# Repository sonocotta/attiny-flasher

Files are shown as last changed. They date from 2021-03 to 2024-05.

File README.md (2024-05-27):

# ATtiny Flasher and ATtiny Flasher Kits project files

Open Source Hardware
Open Source Software

<br />


ATtiny Flasher is a handy device that allows you to use your favorite IDEs and debugging tools when developing for the ATtiny microcontroller. Enjoy the classic Arduino development experience while working with bare metal. Whether you’re a design engineer, a hobbyist, or someone who’s just getting started programming MCUs, ATtiny Flasher can help you get from a great idea to a great implementation—without having to port your code to its intended platform when you’re done

After implementing numerous projects using the wonderful ATtiny family of MCUs, we’ve come away with a number of ideas about how to simplify the process. Our goal is to make ATtiny chips as easy to work with as more "grown up" MCUs:
- We want a traditional serial terminal for debugging. Ideally, we want two—one via serial data transferred to the host over USB, and another via the onboard display.
- We want some GPIO LEDs to play with. In fact, why not have LEDs for all GPIOs?
- Speaking of GPIOs, we want to use the RESET pin as a GPIO too, so we'll need an on-board high-voltage programmer.
- In general, we want to upload code to breadboard-connected devices and see that code in action immediately.
- And finally, since our debugger will be connected to a PC via USB, it should handle 3.3 V and 5 V breadboard power rails as well

## How to use it

### Using onboard socket


- Tiny85 to be programmed 
- Breadboard lines connected to Tiny85 pins 
- LEDs connected to Tiny85 pins 
- Tiny85 Serial monitor displayed on LED as well as sent to host PC 
- Host MCU connection to PC 

### Using breadboard


- Tiny85 to be programmed 
- Breadboard lines connected to Tiny85 pins 
- LEDs connected to Tiny85 pins 
- Tiny85 Serial monitor displayed on LED as well as sent to host PC 
- Host MCU connection to PC 

### Using dedicated ATtiny Flasher Kits


- Tiny85 to be programmed 
- Kit components (addressable leds and 2 push buttons) 
- Breadboard lines connected to Tiny85 pins 
- LEDs connected to Tiny85 pins 
- Tiny85 Serial monitor displayed on LED as well as sent to host PC 
- Host MCU connection to PC 

### Standalone, using onboard ISP Header 

- Use ATTiny Flasher like regular ISP Programmer

## ATTiny Flasher Features

- Flash ATtiny85, ATtiny45, ATtiny25, and ATtiny13 via breadboard or onboard header
- Flash the entire Atmega MCU family using the ISP header
- Flash using Arduino IDE, Platformio, or the IDE of your choice
- Two configurable power rails, either 3.3 V or 5 V
- Supports high-voltage programming
- Supports UPDI programming with dedicated header
- Supports TPI programming (after certain HW modifications)
- Six GPIO "weak" LEDs
- Three flash-status LEDs
- Onboard OLED screen connected to target MCU as a live terminal
- Streams serial data to the host PC as if it were connected directly to the target MCU. (Yes, serial on ATtiny. Even ATtiny13!)
- A buffer IC between target and host MCUs only connects the two while flashing
- Open hardware driven by open source software

## Educational ATtiny Project Kits

Having built a product that ticks all of those boxes, we wanted to put ATtiny through its paces, so we designed a collection of simple, affordable, breadboard-compatible project kits that are easy to understand, fun to build, satisfying to use, and well suited to extension and modification. There are five of them in all, and they are a great way to learn about ATtiny programming:

### Traffic Light: ATtiny85-driven "traffic light"



- Onboard ATTiny85 
- 3 bright LEDs: green, yellow, red (PWM controllable) 
- User-programmable button 
- External input or output 

### Rubber Ducky: ATtiny85-driven "USB rubber ducky" tool capable of emulating keyboard & mouse devices



- Onboard ATTiny85 
- 3 user-programmable buttons 
- USB connector with possibility act as PC keyboard or mouse 

### IR Messenger: ATtiny85-driven IR remote transmitter & receiver



- Onboard ATTiny85 
- 3 user-programmable buttons 
- IR recevier (940nm) 
- IR sender (dual 940nm IR LED) 

### Rainbow LED: ATtiny85-driven circle of addressable LEDs



- Onboard ATTiny85 
- 2 user-programmable buttons 
- 8 individually addressable LEDs (WS2820) 
- External input or output 

### Digital Clock: ATtiny85-driven digital clock


- Onboard ATTiny85 
- 2 user-programmable buttons 
- SPI RTC clock (DS1302) with CR1220 battery 
- 128 individually controllable LEDs (forms matrix, stacks on top) 

## Hardware

Please find more information in the [hardware](/hardware) section

## Firmware

Please find more information in the [software](/firmware) section

## Where to buy

Shortly will be available to order from [Mouser](https://mouser.com).

Later on will be shared on [Tindie](https://www.tindie.com/) store.

## Links

- [Crowd Supply campaign](https://www.crowdsupply.com/sonocotta/attiny-flasher)
- [ATtiny Flasher - Product site](https://sonocotta.com/attiny-flasher/)
- [ATtiny Flasher Kit - Product site](https://sonocotta.com/attiny-flasher-kit/)

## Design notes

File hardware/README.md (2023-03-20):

# ATtiny Flasher and ATtiny Flasher Kits hardware 

Open Source Hardware
Open Source Software

This is hardware design files for ATtiny Flasher project



## Features



1. Host MCU - Atmega328P 
2. Host RESET button 
3. Flashing status indicators 
4. Host USB port - for flashing both TARGET and HOST MCUs 
5. Host ISP header - for direct hardware flashing 
6. OLED screen - connected to Host, when used with stock firmware will output TARGET serial data 
7. Programming mode switches 
8. Target ISP flashing header. Compartible with Atmega and ATTiny Family MCUs 
9. Target socket - alternative to flashing within breadboard. Compartible with Tinyx5 and Tiny13 series. 
10. Power Rails and voltage selectors 
11. TARGET port LED indicators 
12. TARGET breadboard connectors 

## Mode Switches



| Num | Function | ON | OFF |
|----|----|----|----|
| 1 | Serial Bridge between Host and Target. When enabled Serial Data from TARGET MCU will be captured on the HOST MCU (115200 baud rate by default). It will be displayed on the OLED screen, also translated to PC via on-boarde Serial-to-USB chip. When enalbed it will pullup PB3 and PB4 ports on the TARGET, therefore might be required to be off | Enabled | Disabled |
| 2 | High voltage programming. When ON it will use built in 12V boost converter to reset HOST MCU into high voltage programming mode. Using this method you can use PB5 port of ATTINY (normally not usable), however make sure that other components of your device can handle 12V during flashing process. | Low voltage, green status LED blink slowly. | High voltage, green status LED blink rapidly |
| 3 | Programming target. When ON incoming Serial data will be interpretet as STK500 commands and translatred accordingly to TARGET MCU. When OFF it will allow to flash HOST MCU using Arduino bootloader (i.e. like any other Atmega) | Flash TARGET | Flash HOST |

## Board Revisions

This comes in multiple revisions, normally revision of the specific board will be clearly visible on the back side of the PCB.



Customers that have participated in the [Crowd Supply campaign](https://www.crowdsupply.com/sonocotta/attiny-flasher)

Current distribution of board revisions looks like this

| Revision | ATtiny Flasher | Revision | ATtiny Flasher Kits  |
|----|----|----|----|
| A | First idea implementation <br />  | | |
| B | Early production run, first one that is breadboard compatible <br />  | | |
| C | Version which started Crowd Supply campaign, still lacking many features however <br />  | A | First run of the Kits <br />  |
| D | Deep revision of the board with High Voltage programming mode added, however not without mistakes :) <br />  | | |
| E | Home work was done to make HVSP work, few improvements <br />  |  | |
| F | Pre-production version of the board, first having UPDI and TPI hardware support. <br />  | B | Fixups after the first run validation <br />  |
| G | **First batch of boards delivered to backers**. Tested with both UPDI and TPI, however require soldering to run in TPI mode. <br />  | C | **First batch of boards delivered to backers**. One issue is still present on the board, that was fixed using bodge resistor <br />  |
| H | Work in progress. Had to replace CH340E chip with CH340G due to inavailability of the first. **Second batch of boards delivered to backers** | D | Work in progress. Issue with Clock kit was found and fixed |
| J | Work in progress. Based on ATMega32u4 host MCU. | | 

## Pin Definitions

### ATtiny Flasher

Generally pins will differ slightly from revision to revision, and will be defined in [boards.h](/firmware/flasher/attiny-flasher/src/boards.h) file Most essential ones are listed below

| PIN DEF | IO | G, H | J
|----|----|----|----|
| OLED SDA,SCL | IO | PC4,PC5 | PD1,PD0 |
| HOST USB | IO | NA | D+,D- |
| HOST SERIAL | IO | PD0,PD1 | NA | 
| TINY SERIAL TX,RX | IO | PD4,PD5 | PD3,PD3 |
| SPI (TINY PROGRAMMING, SELF PROGRAMMING) CLK,MOSI,MISO | IO | PB5,PB3,PB4 | PB1,PB2,PB3 |
| +12V RESET ENABLE | IO | PD2 | PF1
| TARGET RESET PULL UP,DOWN | O | PB2,PC2 | PF0,PF4
| BUFFER ENABLE | O | PC1 (HIGH for ISP, LOW for HVSP) | PB7 (ISP), PE6 (HVSP) |
| STATUS LEDs | O | PD7,PB0,PB1 | NA |
| RGB LED | O | NA | PC6 |
| UPDI IO | IO | PD6 | PD6 | 
| SERIAL ENABLE INPUT | I | PC3 | PF5 

### ATtiny Flasher Kits 

Each usable pin is subscribed directly on the PCB, like on exmaple below



## Links

- [Crowd Supply campaign](https://www.crowdsupply.com/sonocotta/attiny-flasher)
- [ATtiny Flasher - Product site](https://sonocotta.com/attiny-flasher/)
- [ATtiny Flasher Kit - Product site](https://sonocotta.com/attiny-flasher-kit/)

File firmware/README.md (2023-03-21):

# ATtiny Flasher firmware

Open Source Hardware
Open Source Software

## Introduction

All repos are [Platformio](https://platformio.org/) projects, all tested under Ubuntu 20.04 LTS. 

Most of the repos will utilize multiple environments with different settings for different board revisions. Please refer to **platformio.ini** file within project folder.

For each project please find detailed description using links below

## ATtiny Flasher repos

- [attiny-flasher](/firmware/flasher/attiny-flasher) - main ATtiny Flasher firmware repo
- (WIP) [attiny-flasher-updi](/firmware/flasher/attiny-flasher-updi) - adaptation of [jtag2updi](https://github.com/ElTangas/jtag2updi) repo that can be used with Flasher to programm UPDI enabled MCUs
- (WIP) [attiny-flasher-tpi](/firmware/flasher/attiny-flasher-tpi) - TPI communication testing, requires soldering 0-Ohm resistor to be enabled on tyhe hardware level
- (DEBUGGING) [attiny-flasher-arduino-isp](/firmware/flasher/attiny-flasher-arduino-isp) - Original [ArduinoISP](https://www.arduino.cc/en/Tutorial/BuiltInExamples/ArduinoISP) repo adopted to be used with ATtiny Flasher
- (DEBUGGING) [attiny-flasher-test-reset-states](/firmware/flasher/attiny-flasher-test-reset-states) - Firmware that cycle through RESET modes (for HW testing and debuging)
- (DEBUGGING) [attiny-flasher-test-reset-fuses](/firmware/flasher/attiny-flasher-test-reset-fuses) - Firmware that clears out fuse settings on RESET-disabled Tinys (for HWSP testing and debuging)
- (DEBUGGING) [attiny-serial-demo](/firmware/flasher/attiny-serial-demo) - Demo formware for TARGET MCUs that blinks all available LEDs and sends out Serial communications (for HW testing and debuging) 
- (DEBUGGING) [attiny-serial-demo-naked](/firmware/flasher/attiny-serial-demo-naked) - same as above but Framework-less

## ATtiny Flasher Kits repos

- [attiny-bme280-vs-oled](/firmware/kits/attiny-bme280-vs-oled) - Demo firmware that reads BME280 sensor data and sends it to TINY-connected OLED screen
- [attiny-ir-messenger-send-receive](/firmware/kits/attiny-ir-messenger-send-receive) - Receive and send back IR communications (IR Messenger project Kit)
- [attiny-ir-messenger-send](/firmware/kits/attiny-ir-messenger-send) - Send IR communications (IR Messenger project Kit)
- [attiny-led-matrix-demo](/firmware/kits/attiny-led-matrix) - Demo of LED Matrix (Digital Clock kit)
- [attiny-led-matrix-game-of-life](/firmware/kits/attiny-led-matrix-game-of-life) - Demo of LED Matrix [game of life](https://en.wikipedia.org/wiki/Conway%27s_Game_of_Life) (Digital Clock kit)
- [attiny-led-matrix-rtc-clock](/firmware/kits/attiny-led-matrix-rtc-clock) - RTC clock demo firmware (Digital Clock kit)
- [attiny-led-matrix-rtc-clock-set](/firmware/kits/attiny-led-matrix-rtc-clock-set) - 'Set the time' firmware (Digital Clock kit)
- [attiny-led-matrix-text](/firmware/kits/attiny-led-matrix-text) - Demo of the text mode (Digital Clock kit)
- [attiny-rainbow-led](/firmware/kits/attiny-rainbow-led) - Demo firmware of different RGB LED modes (Rainbow Led project kit)
- [attiny-rainbow-led-demo](/firmware/kits/attiny-rainbow-led-demo) - Spinning rainbow demo (Rainbow Led project kit)
- [attiny-rainbow-led-light](/firmware/kits/attiny-rainbow-led-light) - Lightweight library sample that works with Tiny13 (Rainbow Led project kit)
- [attiny-rubber-ducky-keyboard](/firmware/kits/attiny-rubber-ducky-keyboard) - Keyboard emulator demo (Rubber Ducky project kit)
- [attiny-rubber-ducky-mouse](/firmware/kits/attiny-rubber-ducky-mouse) - Mouse emulator demo  (Rubber Ducky project kit)
- [attiny-traffic-light](/firmware/kits/attiny-traffic-light) - Traffic light demo firmware (Traffic Light project kit)

## How to flash

### Recomended: Using Platformio

All firmware files in this repo are [Platformio](https://platformio.org/) projects. This is a preferred tool to be used together with ATtiny Flasher, since it generally hadles better than our beloved Arduino IDE
- It doesn't require manual installation of new boards, it is enough to mention your board in the project configuration and Platformio will pull full framework automatically
- Same goes for the required libraries, just list your dependencies in the project config, Platformio will pull the latest versions
- It is a grown-up code editor, with the possibilities to look up for library sources and adding multiple source files to your project to create good structure.
- It allows to fine-tune build and upload settings as well as many more parameters.

To install Platformio simply add an extension to VS Code

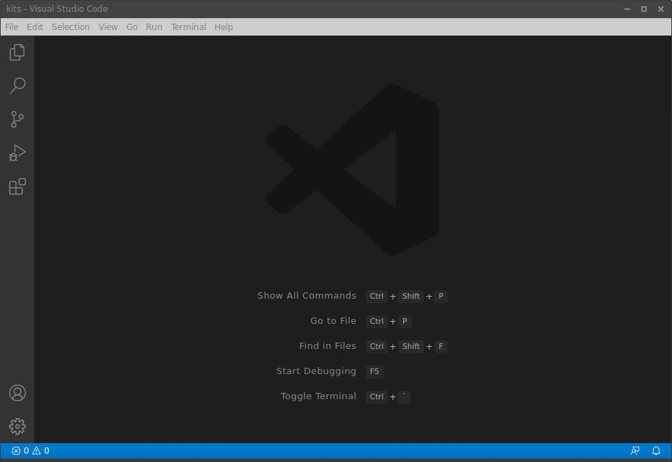
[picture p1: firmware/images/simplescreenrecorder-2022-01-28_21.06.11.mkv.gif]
Install Platformio


#### Flashing Kits using Platformio

Simply open project in the Platformio IDE and run `Platformio: Build` and `Platformio: Upload` tasks. All the relevant settings can be found in `platformio.ini` file in the project folder.

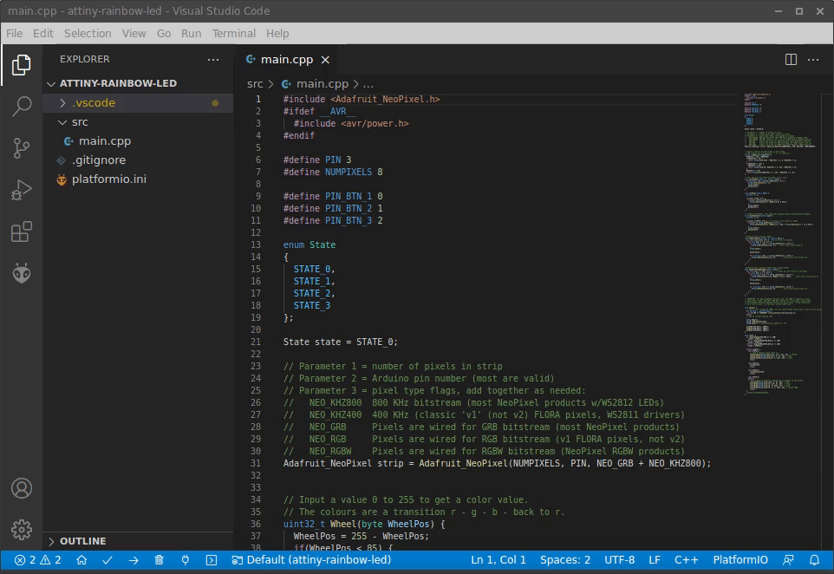
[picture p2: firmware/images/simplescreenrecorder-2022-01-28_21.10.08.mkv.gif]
Build and Upload using Platformio


#### Using Platformio to update Flasher firmware

Open [attiny-flasher](/firmware/flasher/attiny-flasher) folder in Platformio IDE. Find in the Platformio panel your revision of the board (Single letter, usually G, H, J etc is printed in the back side of the PCB). Use the physical switch on the Flasher to select self-programming mode.



Run `Upload` task.

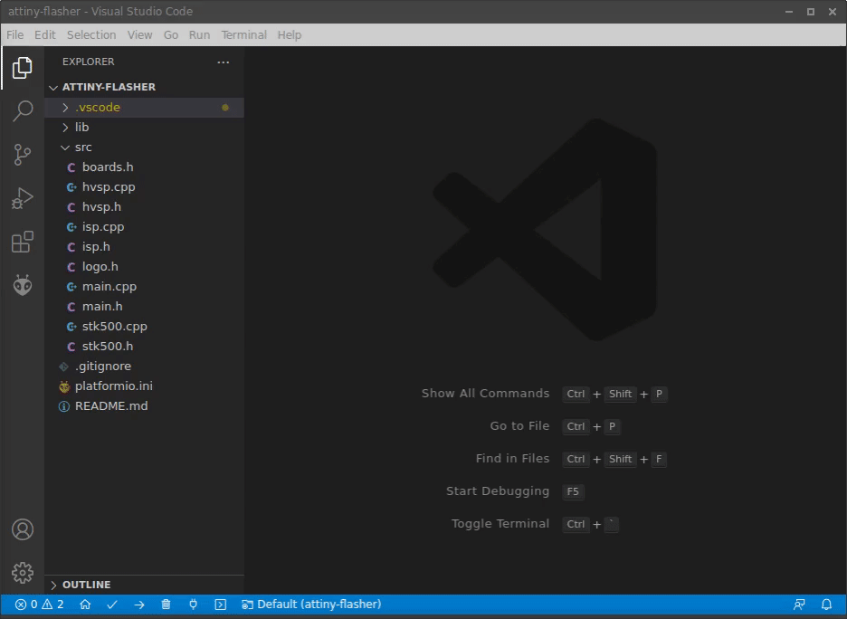
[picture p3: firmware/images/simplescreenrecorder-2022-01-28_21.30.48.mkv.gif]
Updating firmware using Platformio


### Using Arduino IDE

All Flasher Kits are built on ATTINY85 MCU which is not supported by default in Arduino IDE. Therefore first you need to add ATTINY85 support to your Arduino IDe using board manager. Use this link json configuration
```
https://raw.githubusercontent.com/damellis/attiny/ide-1.6.x-boards-manager/package_damellis_attiny_index.json
```

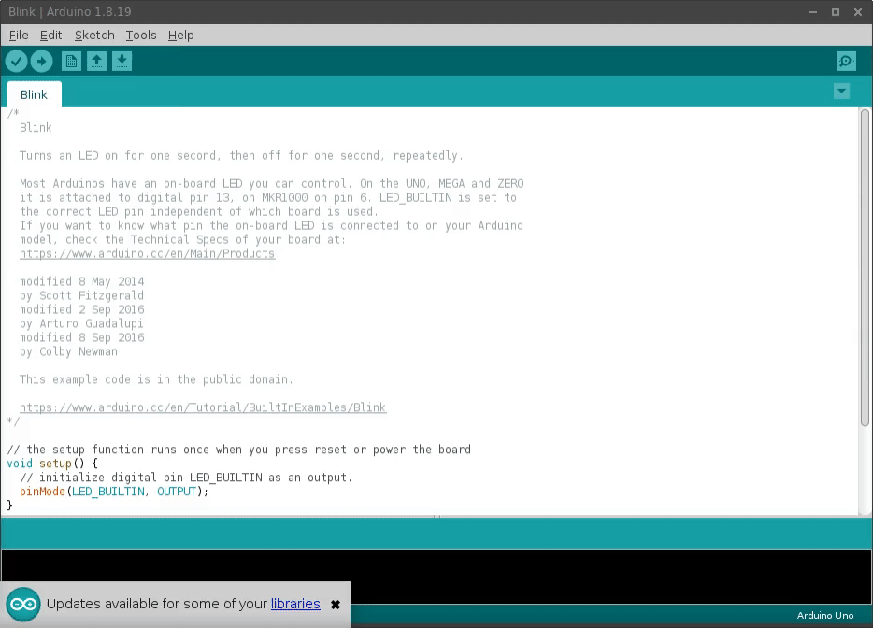
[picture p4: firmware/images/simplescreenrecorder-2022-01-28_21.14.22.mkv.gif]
Adding ATTiny85 support to Arduino IDE


#### Flasher Configuration

By default ATTiny Flasher would expect 115200 baudrate when programming Flasher Projects. Arduino IDE in turn uses 19200 baud rate for the same. This can be fixed by modifying Arduino IDE internal configs (which is not recomended) or by flashing Flasher with updated baud rate

Updating firmware using Platformio

After this is done you may use `Arduino as ISP` programmer in the Arduino IDE with no modifications.

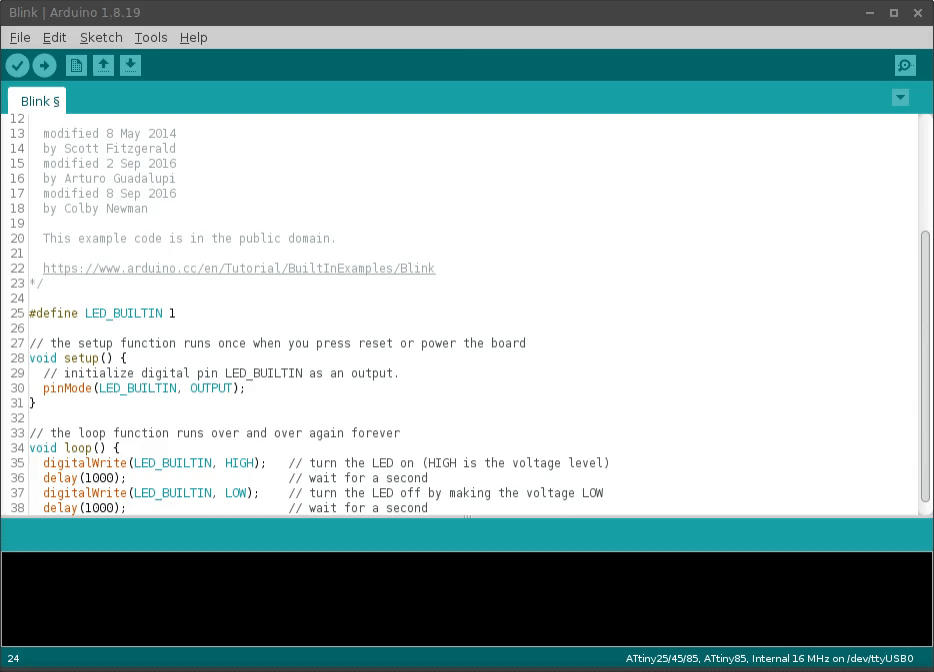
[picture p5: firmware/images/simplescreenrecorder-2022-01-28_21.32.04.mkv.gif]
Flashing using Arduino IDE


### Using avrdude

If you prefer to flash Kits usging pure console, you can use `avrdude` with the proper configuration (similar to what Platformio does under the hood)

Assuming you have built `firmware.hex` and your upload port to be `/dev/ttyUSB0`
```
avrdude -P/dev/ttyUSB0 -b115200 -v -p attiny85 -c stk500v1 -b 115200 -e -D -U flash:w:firmware.hex:i
```

## Links

- [Crowd Supply campaign](https://www.crowdsupply.com/sonocotta/attiny-flasher)
- [ATtiny Flasher - Product site](https://sonocotta.com/attiny-flasher/)
- [ATtiny Flasher Kit - Product site](https://sonocotta.com/attiny-flasher-kit/)

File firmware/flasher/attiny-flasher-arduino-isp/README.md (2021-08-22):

## attiny-flasher-arduino-isp

This is basic ArduinoISP code adopted to be executed on [ATtiny Flasher](https://sonocotta.com/attiny-flasher/).

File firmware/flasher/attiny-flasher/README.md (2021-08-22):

## attiny-flasher

This is firmware code for [ATtiny Flasher](https://sonocotta.com/attiny-flasher/).

It is based on Arduino Framework and currently cupports ISP flasing using STK500v1 protocol in both high voltage and low voltage modes.

I'm trying to keep support of all board revisions to simplify board development and testing, therefore list of build configurations is growing all the time. 

Each new revision of the board is adding some capabilities and more code required to support added features.

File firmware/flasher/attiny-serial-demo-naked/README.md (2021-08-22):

## attiny-serial-demo

This is basic led-blinking and/or serial messaging app that is used to verify [ATtiny Flasher](https://sonocotta.com/attiny-flasher/) capabilities to flash different MCUs. 

It is not using any frameworks but works directly on HW and therefore it is compatible with all the supported MCUs. It is quite usefull for testing and debugging purposes.

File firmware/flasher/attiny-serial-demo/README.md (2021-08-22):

## attiny-serial-demo

This is basic led-blinking and/or serial messaging app that is used to verify [ATtiny Flasher](https://sonocotta.com/attiny-flasher/) capabilities to flash different MCUs. 

It is based on Arduino Framework and therefore is not compatible with all the supported MCUs, but it is quite usefull for testing and debugging purposes

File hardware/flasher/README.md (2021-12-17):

# ATtiny Flasher hardware 

Open Source Hardware
Open Source Software

Please find description on each revision [one level above](/hardware)

## Links

- [Crowd Supply campaign](https://www.crowdsupply.com/sonocotta/attiny-flasher)
- [ATtiny Flasher - Product site](https://sonocotta.com/attiny-flasher/)
- [ATtiny Flasher Kit - Product site](https://sonocotta.com/attiny-flasher-kit/)

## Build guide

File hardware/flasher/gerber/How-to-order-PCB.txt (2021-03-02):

How to Order PCB

Please refer to:
https://docs.easyeda.com/en/PCB/Order-PCB

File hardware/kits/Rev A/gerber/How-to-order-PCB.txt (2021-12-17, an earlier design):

How to Order PCB

Please refer to:
https://docs.easyeda.com/en/PCB/Order-PCB

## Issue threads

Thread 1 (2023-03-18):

Firmware documentation problem

koocotte, 2023-03-18:
In file [attiny-flasher](https://github.com/sonocotta/attiny-flasher)/hardware/README.md file, section "Mode Switches";

Text said "When ON (...) TARGET MCU. When OFF it will allow to flash HOST MCU";

but in the ON column, there is "Flash HOST" and in the OFF one: "Flash TARGET"

Closed 2023-03-20.

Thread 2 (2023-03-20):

Flashing firmware result in "error" LED

koocotte, 2023-03-20:
Hello.

I don't know if here is the best place to try to solve this sort of problem.

I tried to re-flash my attiny-flasher rev G to use 19200 bps to work with the arduino IDE.

As specified on firmware/README.md, I put all 3 switch 'OFF' and updated hardware/README.md with "#define BAUDRATE_IN 19200".
In platformio, the Build and Upload task where successfull.

But on reboot; there is no more draw on the screen and the "ERR" led is red.

Here are the Upload log (don't know if it's useful)

[attiny-upload.txt](https://github.com/sonocotta/attiny-flasher/files/11015535/attiny-upload.txt)

anabolyc, 2023-03-20:
Hi @koocotte .
Quick health check:
- please make sure your HW version is G
- which folder (project) you took for the repo?

koocotte, 2023-03-21:
Hello,

"ATTINY FLASHER
REV G" is written on the back of the board

Here is the repo i use:
```
seb@octarine:~/tmp/attiny-flasher/firmware/flasher/attiny-flasher$ git remote -v
origin  https://github.com/sonocotta/attiny-flasher/ (fetch)
origin  https://github.com/sonocotta/attiny-flasher/ (push)
seb@octarine:~/tmp/attiny-flasher/firmware/flasher/attiny-flasher$ git pull
Already up to date.
```
In Platformio (the ant-face tab), I use the file `attiny-flasher/firmware/flasher/attiny-flasher/platformio.ini` and the task `atmega328-tiny-rev-g/General/Upload`

anabolyc, 2023-03-21:
Hi @koocotte. I just notices, that I did quite a few changes in the fork, rather than in this repo. I just committed "sync" changeset. It doesn't address your issue directly, but it will update your code to the version I'm using.
Could you please pull the latest code and flash firmware once again. Please note if dependency graph will stay the same or become shorter.

Closed 2023-03-22.

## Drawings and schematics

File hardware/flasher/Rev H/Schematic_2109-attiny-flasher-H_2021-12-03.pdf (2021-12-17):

LED INDICATORS | FLASHING BUFFER

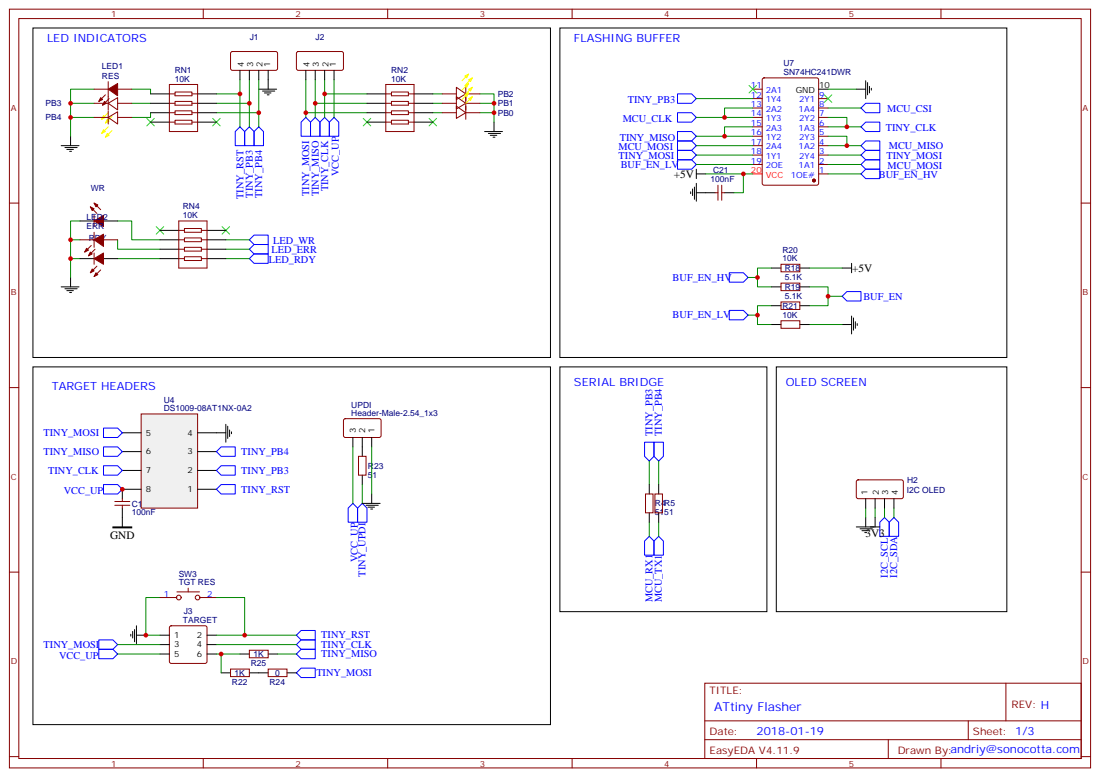
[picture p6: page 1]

HOST MCU | MODE SWITCHES

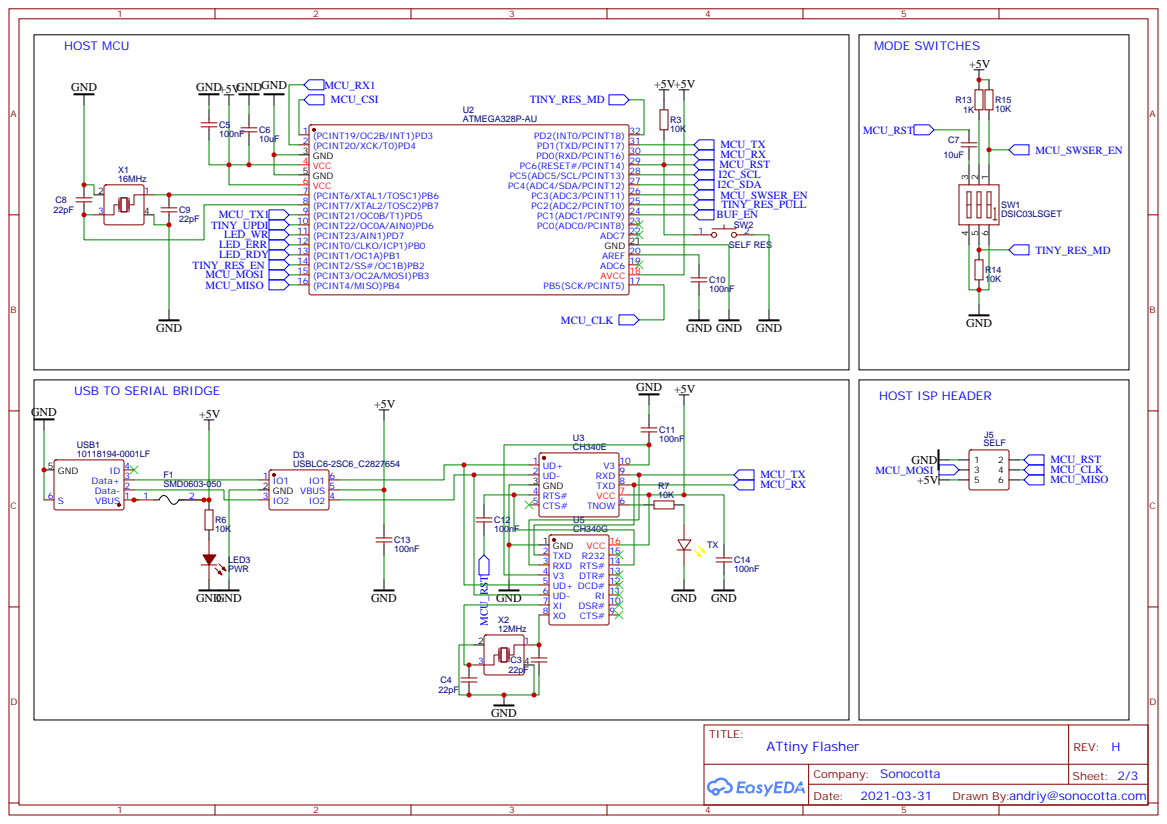
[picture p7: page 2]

DSR# 10 RI 11 DCD# 12 DTR# 13 RTS# 14 R232 15 VCC 16

Drawn By:andriy@sonocotta.com

## RESET TARGET CIRCUIT

## POWER INDICATORS

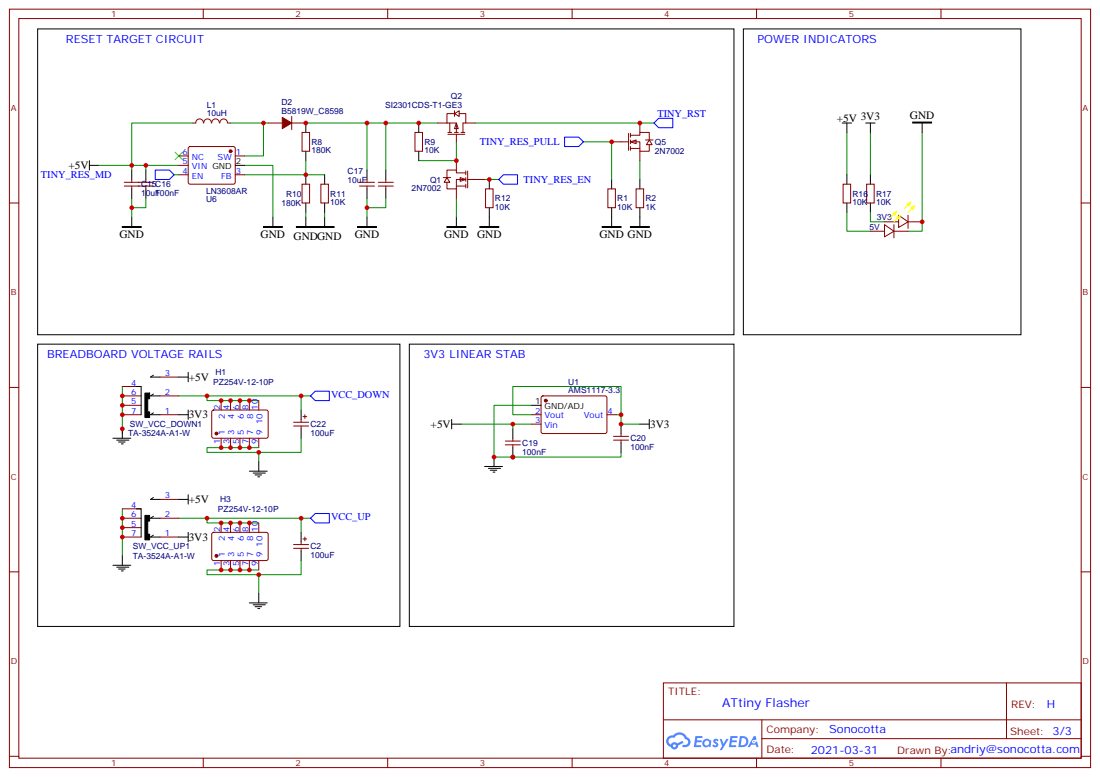
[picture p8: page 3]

Drawn By:andriy@sonocotta.com

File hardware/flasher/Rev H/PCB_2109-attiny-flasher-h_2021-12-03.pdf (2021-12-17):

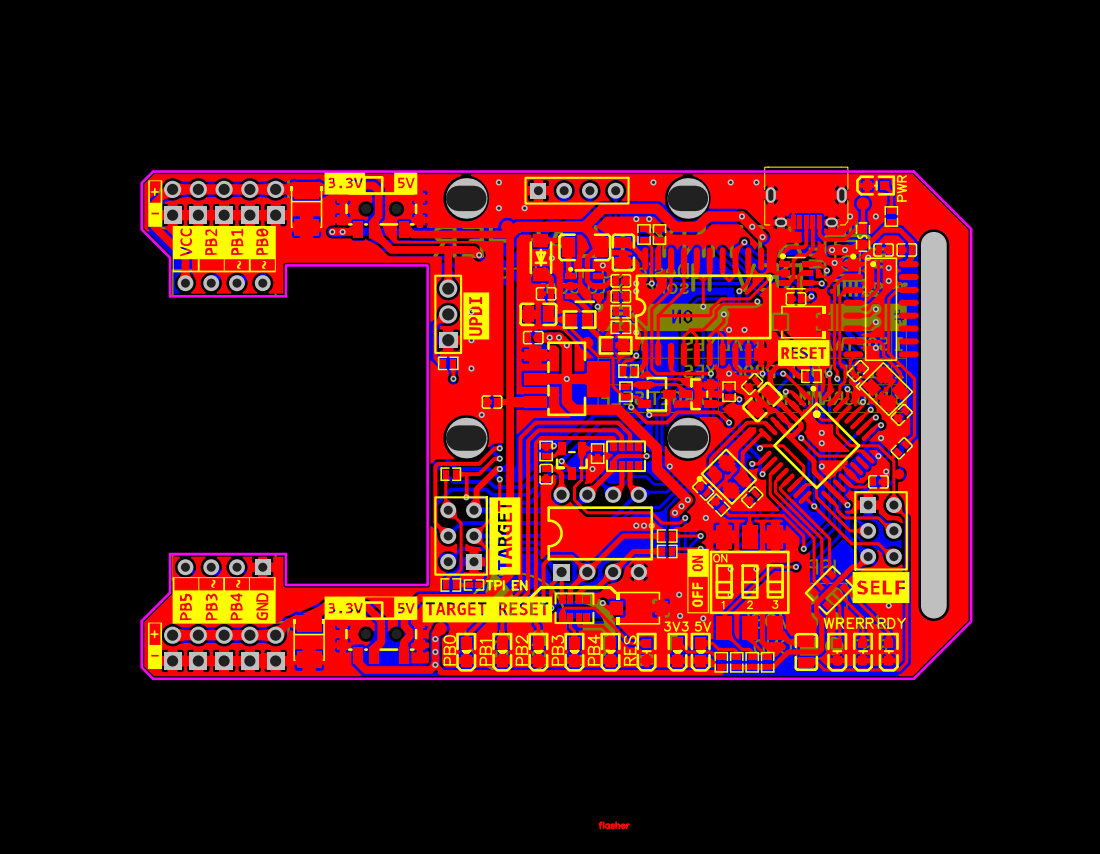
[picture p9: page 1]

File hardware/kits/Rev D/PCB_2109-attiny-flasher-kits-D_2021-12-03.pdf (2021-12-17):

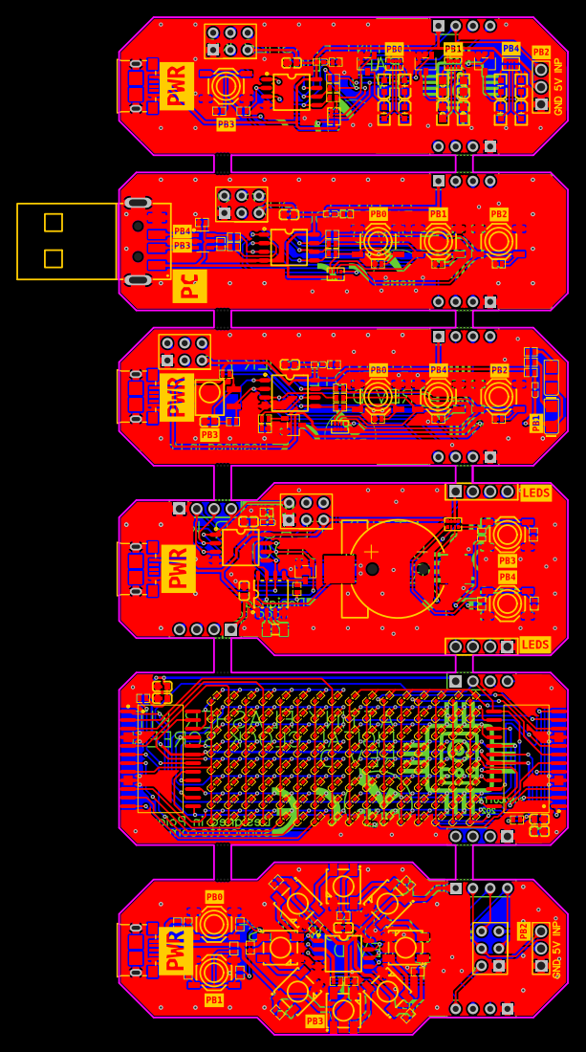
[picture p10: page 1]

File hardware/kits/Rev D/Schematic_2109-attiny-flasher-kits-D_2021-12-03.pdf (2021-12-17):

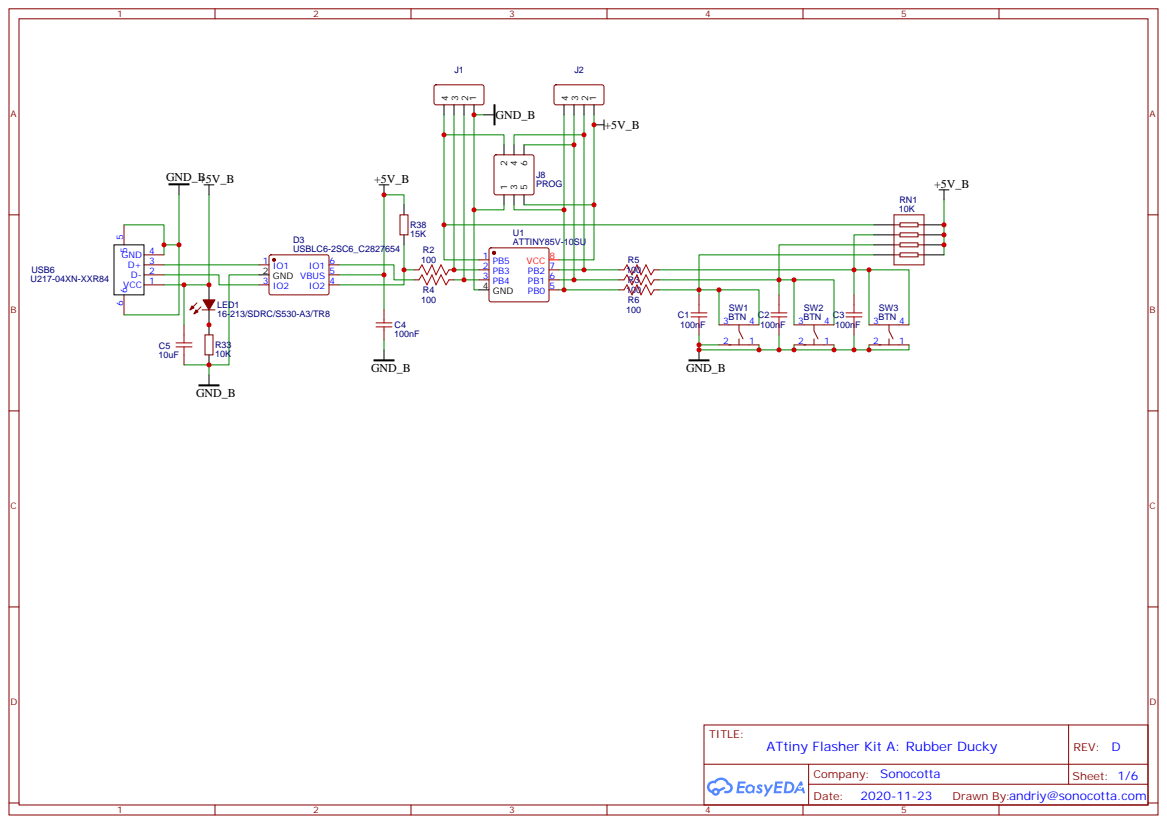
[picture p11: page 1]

Drawn By:andriy@sonocotta.com

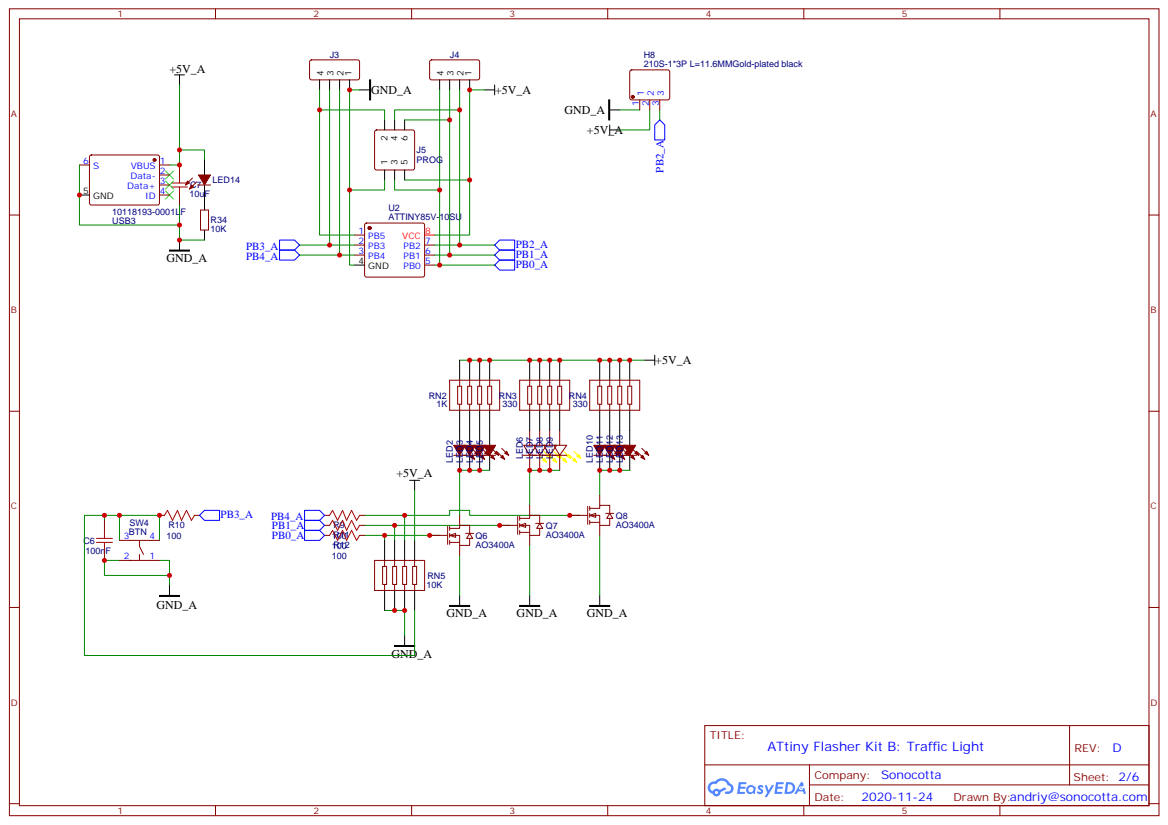
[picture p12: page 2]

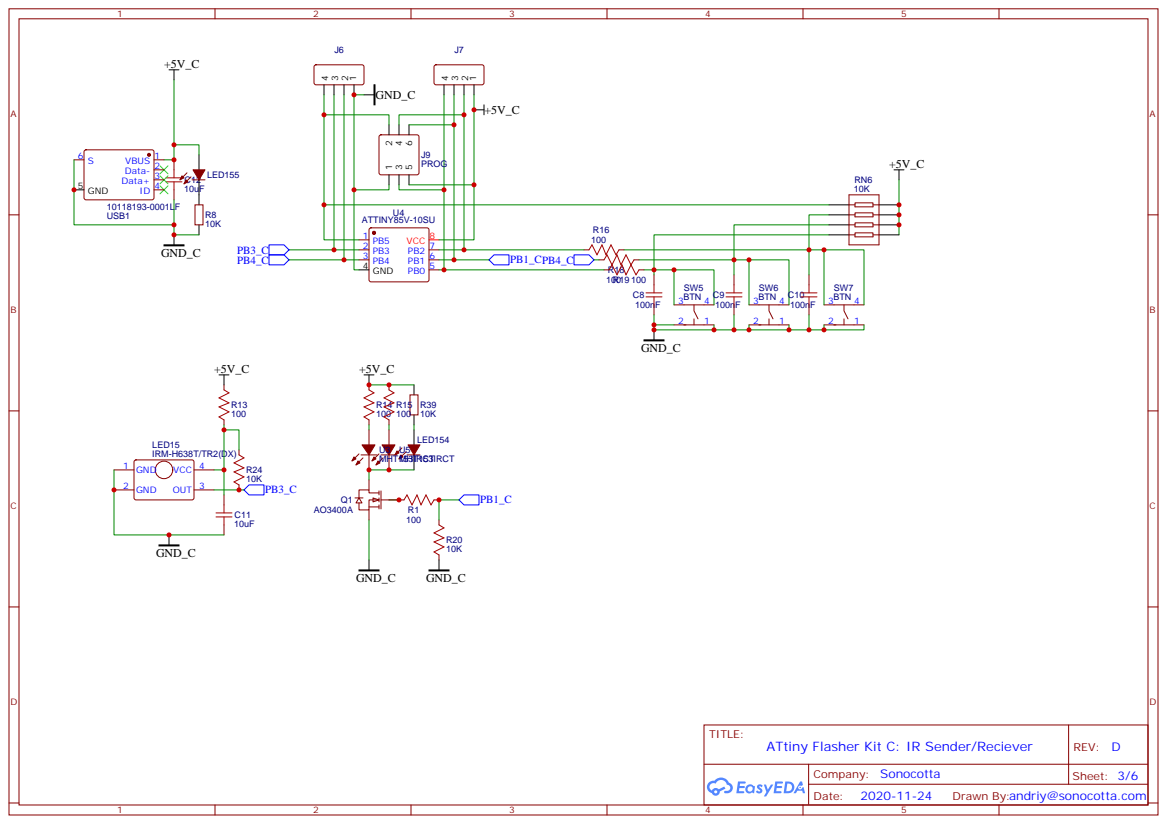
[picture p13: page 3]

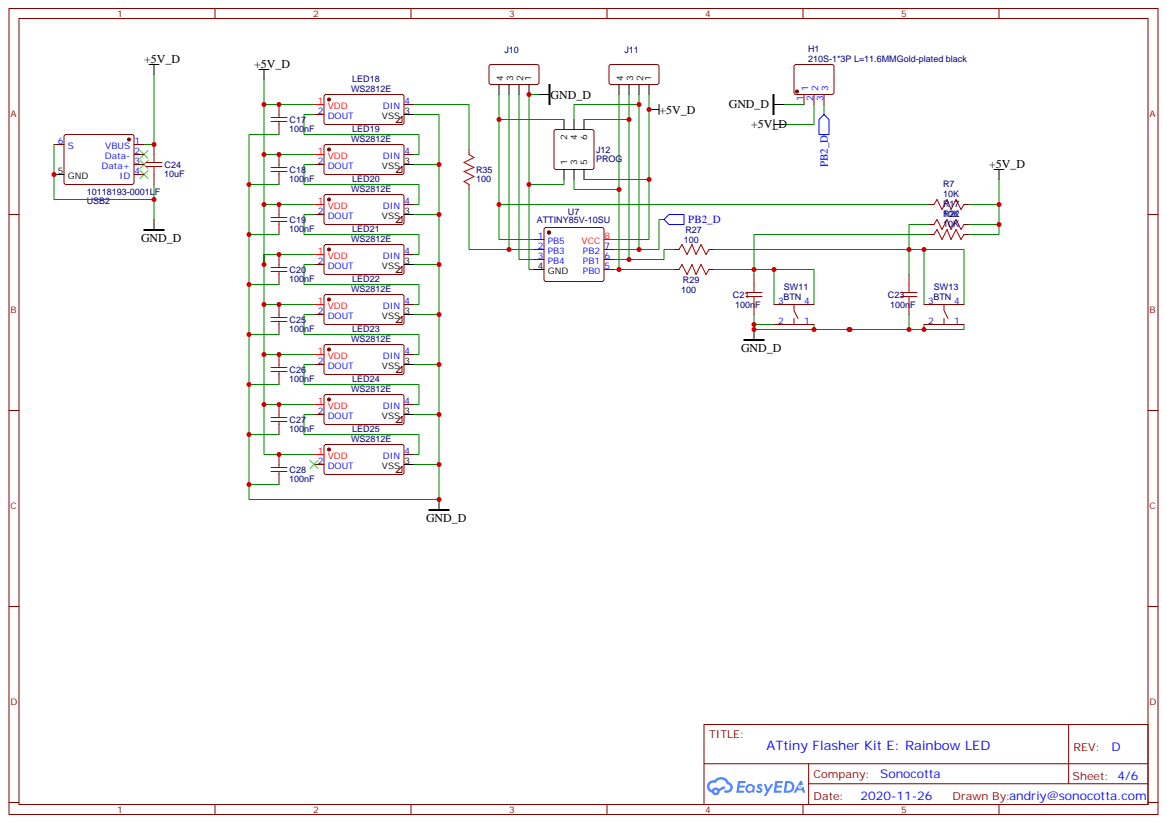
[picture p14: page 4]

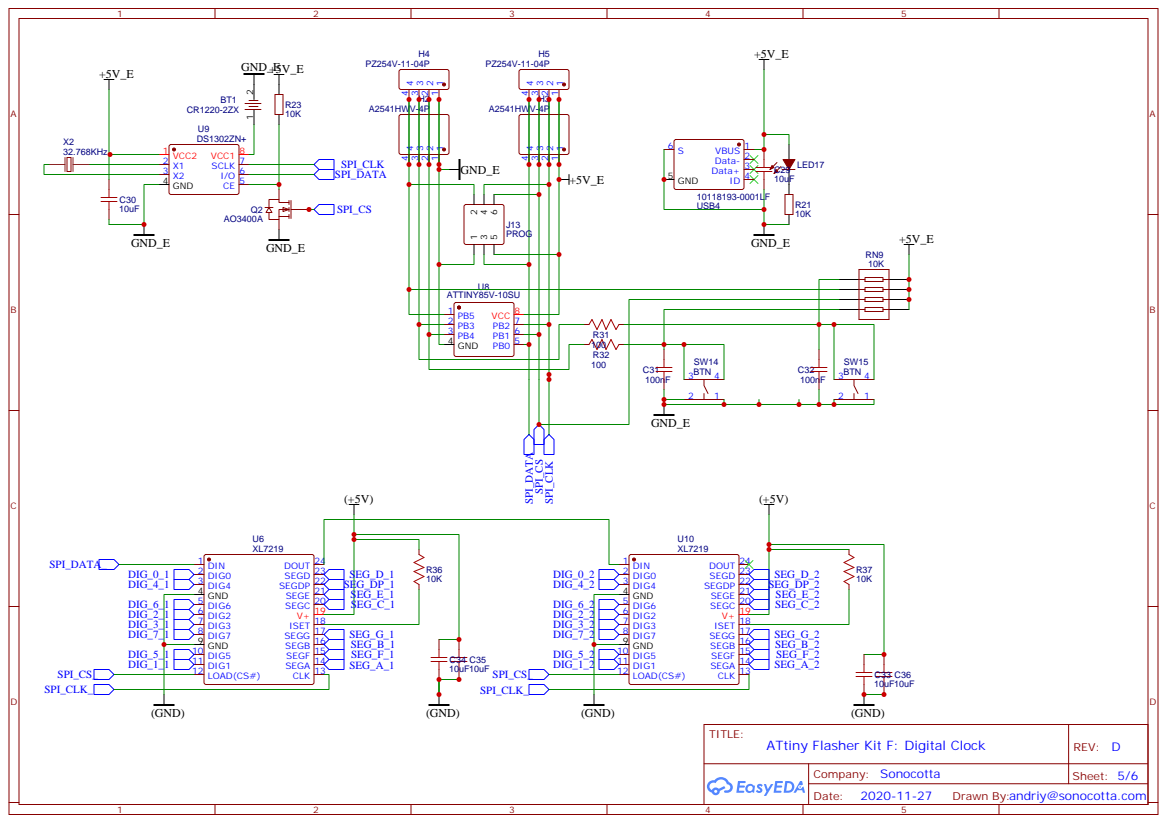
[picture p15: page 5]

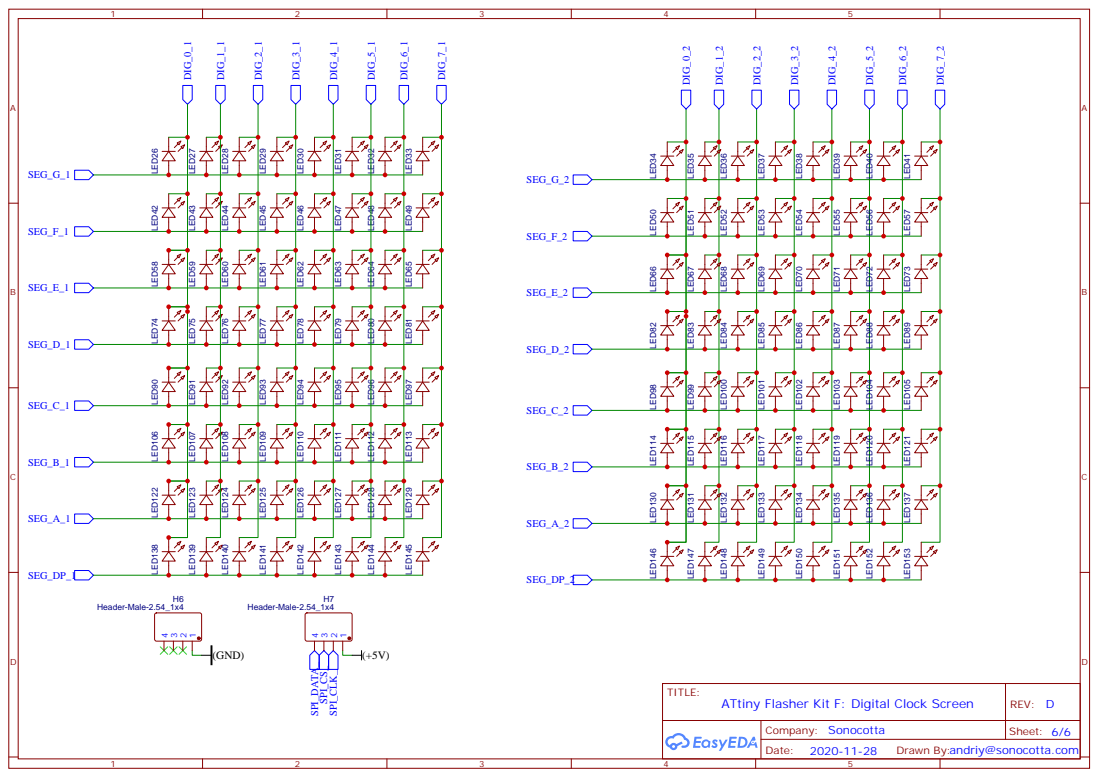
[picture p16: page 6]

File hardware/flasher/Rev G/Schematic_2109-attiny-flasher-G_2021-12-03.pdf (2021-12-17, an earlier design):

LED INDICATORS | FLASHING BUFFER

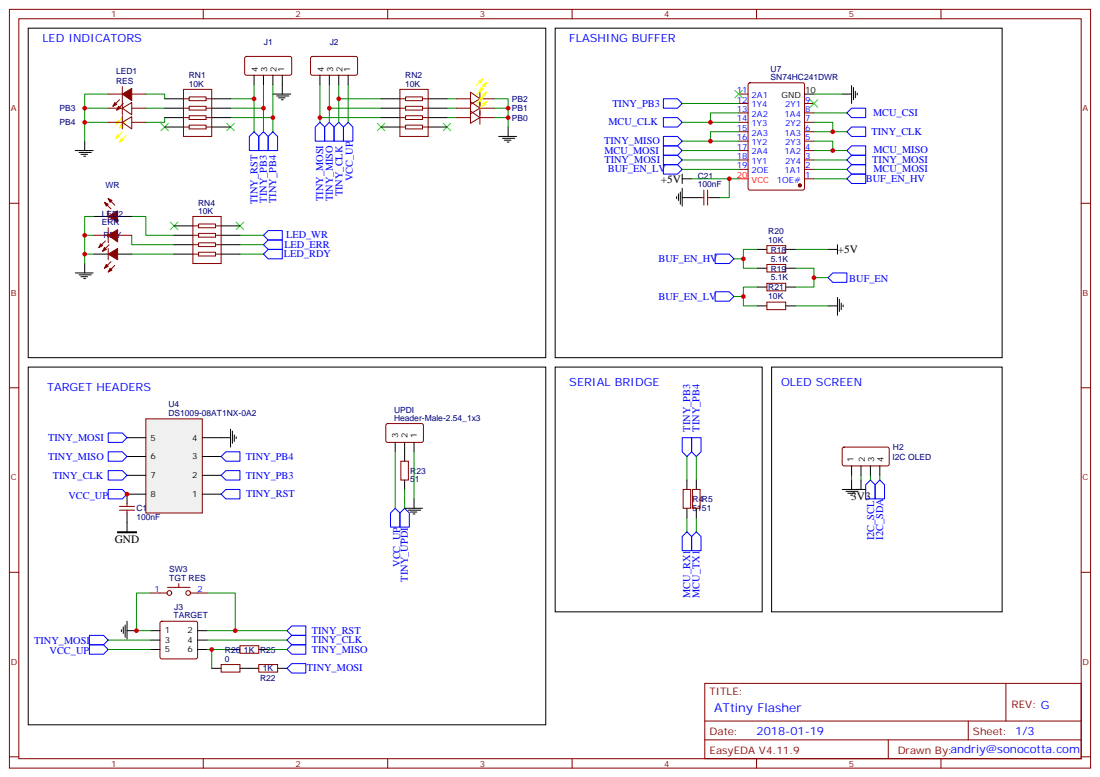
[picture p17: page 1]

HOST MCU | MODE SWITCHES


HOST ISP HEADER USB TO SERIAL BRIDGE

Drawn By:andriy@sonocotta.com

## RESET TARGET CIRCUIT

## POWER INDICATORS


Drawn By:andriy@sonocotta.com



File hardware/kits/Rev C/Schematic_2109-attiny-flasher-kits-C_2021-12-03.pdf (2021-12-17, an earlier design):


Drawn By:andriy@sonocotta.com









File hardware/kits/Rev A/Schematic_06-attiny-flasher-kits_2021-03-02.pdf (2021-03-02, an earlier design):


Drawn By: andrey.malyshenko@gmail.com


Drawn By: andrey.mal






Drawn By: andrey.mal

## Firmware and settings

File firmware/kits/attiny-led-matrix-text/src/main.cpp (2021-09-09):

#include <Arduino.h>
#include "main.h"

#define SCREEN_CNT 2

#define byte uint8_t
#define FONT8X8 font8x8_ib8x8u

const byte ROTATION_0 = 0;   // wires at the left
const byte ROTATION_90 = 1;  // wires at the top
const byte ROTATION_180 = 2; // wires at the right
const byte ROTATION_270 = 3; // wires at the bottom

const byte *getImage(byte ch)
{
    if (ch < 128)
    {
        return FONT8X8[ch];
    }
    if (ch >= 128 && ch < 160)
    {
        // miscellaneous
        ch -= 128;
        if (ch < sizeof(font8x8_misc) / 8)
        {
            return font8x8_misc[ch];
        }
        return FONT8X8[0]; // valeur par défaut
    }
    return FONT8X8[ch - 160 + 128];
}

inline byte reverseBits(byte b)
{
    byte inv = 0;
    for (int j = 0; j < 8; ++j)
    {
        inv <<= 1;
        if (b & 0x1)
            inv |= 1;
        b >>= 1;
    }
    return inv;
}

void rotateChar90(const byte *image, byte newb[8])
{
    for (int i = 0; i < 8; ++i)
    {
        newb[i] = 0;
        for (int j = 0; j < 8; ++j)
        {
            byte b = pgm_read_byte_near(image + j);
            newb[i] |= (b & (1 << i)) ? 1 << (7 - j) : 0;
        }
    }
}

void rotateChar270(const byte *image, byte newb[8])
{
    for (int i = 0; i < 8; ++i)
    {
        newb[i] = 0;
        for (int j = 0; j < 8; ++j)
        {
            byte b = pgm_read_byte_near(image + j);
            newb[i] |= (b & (1 << (7 - i))) ? 1 << j : 0;
        }
    }
}

void printChar(LedControl &lc, int addr, byte ch)
{
    const byte *image = getImage(ch);
    for (int i = 0; i < 8; i++)
    {
        byte b = pgm_read_byte_near(image + i);
        lc.setRow(addr, i, b);
    }
}

void printChar(LedControl &lc, int addr, byte ch, byte rotate)
{
    const byte *image = getImage(ch);
    if (rotate == ROTATION_0)
    {
        for (int i = 0; i < 8; ++i)
        {
            byte b = pgm_read_byte_near(image + i);
            lc.setRow(addr, i, b);
        }
    }
    else if (rotate == ROTATION_90)
    {
        byte newb[8];
        rotateChar90(image, newb);
        for (int i = 0; i < 8; ++i)
        {
            lc.setRow(addr, i, newb[i]);
        }
    }
    else if (rotate == ROTATION_180)
    {
        for (int i = 0; i < 8; ++i)
        {
            byte b = pgm_read_byte_near(image + 7 - i);
            lc.setRow(addr, i, reverseBits(b));
        }
    }
    else if (rotate == ROTATION_270)
    {
        byte newb[8];
        rotateChar270(image, newb);
        for (int i = 0; i < 8; ++i)
        {
            lc.setRow(addr, i, newb[i]);
        }
    }
}

class StrBase
{
  protected:
    const char *str_;
    size_t len_;

  public:
    StrBase() = default;

  protected:
    size_t length() const
    {
        return len_;
    }
    virtual byte at(size_t) const = 0;

  private:
    void displayString0(LedControl &lc, int addr, unsigned long wait) const;
    void displayString90(LedControl &lc, int addr, unsigned long wait) const;
    void displayString180(LedControl &lc, int addr, unsigned long wait) const;
    void displayString270(LedControl &lc, int addr, unsigned long wait) const;

  public:
    void displayString(LedControl &lc, int addr, unsigned long wait, bool scroll, byte rotate = ROTATION_0) const
    {
        if (scroll)
        {
            if (rotate == ROTATION_0)
                displayString0(lc, addr, wait);
            else if (rotate == ROTATION_90)
                displayString90(lc, addr, wait);
            else if (rotate == ROTATION_180)
                displayString180(lc, addr, wait);
            else if (rotate == ROTATION_270)
                displayString270(lc, addr, wait);
        }
        else
        {
            for (size_t i = 0; i < length(); ++i)
            {
                printChar(lc, addr, at(i), rotate);
                delay(wait);
            }
        }
    }
    void printString(LedControl &lc, int addr, unsigned long wait, byte rotate = ROTATION_0) const;
};

// string stored in data segment
class StrD : public StrBase
{
  public:
    explicit StrD(const char *str)
    {
        str_ = str;
        len_ = strlen(str);
    }

    virtual byte at(size_t i) const override
    {
        if (i < len_)
            return str_[i];
        return 0;
    }
};

// string with PROGMEM attribute (stored in code segment)
class StrP : public StrBase
{
  public:
    explicit StrP(const char *str)
    {
        str_ = str;
        len_ = strlen_P(str);
    }

    virtual byte at(size_t i) const override
    {
        if (i < len_)
            return pgm_read_byte_near(str_ + i);
        return 0;
    }
};

void StrBase::displayString0(LedControl &lc, int addr, unsigned long wait) const
{
    wait /= 8;
    unsigned o;
    for (o = 0; o < length() - 1; ++o)
    {
        const byte *image1 = getImage(at(o));
        const byte *image2 = getImage(at(o + 1));

        for (int offset = 0; offset < 8; ++offset)
        {
            for (int i = 0; i < 8; ++i)
            {
                byte b;

                if (offset == 0)
                {
                    b = pgm_read_byte_near(image1 + i);
                }
                else
                {
                    byte b1 = pgm_read_byte_near(image1 + i);
                    byte b2 = pgm_read_byte_near(image2 + i);
                    b = (b1 << offset) | (b2 >> (8 - offset));
                }

                lc.setRow(addr, i, b);
            }
            delay(wait);
        }
    }

    // affiche le dernier caractère entièrement
    printChar(lc, addr, at(o));
    delay(wait);
}

void StrBase::displayString90(LedControl &lc, int addr, unsigned long wait) const
{
    wait /= 8;
    unsigned o;
    for (o = 0; o < length() - 1; ++o)
    {
        const byte *image1 = getImage(at(o));
        const byte *image2 = getImage(at(o + 1));

        byte newb1[8];
        byte newb2[8];
        rotateChar90(image1, newb1);
        rotateChar90(image2, newb2);

        for (int offset = 0; offset < 8; ++offset)
        {
            for (int i = 0; i < 8; ++i)
            {
                if (offset <= i)
                    lc.setRow(addr, i, newb1[i - offset]);
                else
                    lc.setRow(addr, i, newb2[i + 8 - offset]);
            }
            delay(wait);
        }
    }

    // affiche le dernier caractère entièrement
    printChar(lc, addr, at(o), ROTATION_90);
    delay(wait);
}

void StrBase::displayString180(LedControl &lc, int addr, unsigned long wait) const
{
    wait /= 8;
    unsigned o;
    for (o = 0; o < length() - 1; ++o)
    {
        const byte *image1 = getImage(at(o));
        const byte *image2 = getImage(at(o + 1));

        for (int offset = 0; offset < 8; ++offset)
        {
            //for (int i = 7; i >= 0; --i)
            for (int i = 0; i < 8; ++i)
            {
                byte b;

                if (offset == 0)
                {
                    b = pgm_read_byte_near(image1 + 7 - i);
                }
                else
                {
                    byte b1 = pgm_read_byte_near(image1 + 7 - i);
                    byte b2 = pgm_read_byte_near(image2 + 7 - i);
                    b = (b1 << offset) | (b2 >> (8 - offset));
                }

                lc.setRow(addr, i, reverseBits(b));
            }
            delay(wait);
        }
    }

    // affiche le dernier caractère entièrement
    printChar(lc, addr, at(o), ROTATION_180);
    delay(wait);
}

void StrBase::displayString270(LedControl &lc, int addr, unsigned long wait) const
{
    wait /= 8;
    unsigned o;
    for (o = 0; o < length() - 1; ++o)
    {
        const byte *image1 = getImage(at(o));
        const byte *image2 = getImage(at(o + 1));

        byte newb1[8];
        byte newb2[8];
        rotateChar270(image1, newb1);
        rotateChar270(image2, newb2);

        for (int offset = 0; offset < 8; ++offset)
        {
            for (int i = 0; i < 8; ++i)
            {
                if (offset - (7 - i) <= 0)
                    lc.setRow(addr, i, newb1[7 + offset - (7 - i)]);
                else
                    lc.setRow(addr, i, newb2[offset - (7 - i) - 1]);
            }
            delay(wait);
        }
    }

    // affiche le dernier caractère entièrement
    printChar(lc, addr, at(o), ROTATION_270);
    delay(wait);
}

void StrBase::printString(LedControl &lc, int addr, unsigned long wait, byte rotate) const
{
    for (size_t i = 0; i < length(); ++i)
    {
        printChar(lc, addr, at(i), rotate);
        delay(wait);
    }
}

// wrappers

// PROGMEM strings
void displayString_P(LedControl &lc, const char *str, int addr, unsigned long wait, bool scroll, byte rotate)
{
    StrP(str).displayString(lc, addr, wait, scroll, rotate);
}

// DATA strings
void displayString(LedControl &lc, const char *str, int addr, unsigned long wait, bool scroll, byte rotate)
{
    StrD(str).displayString(lc, addr, wait, scroll, rotate);
}

const char texte[] PROGMEM = "Hello, World!";

void setup()
{
    for (uint8_t addr = 0; addr < SCREEN_CNT; addr++) {
        lc.shutdown(addr, false);
        /* Set the brightness to a medium values */
        lc.setIntensity(addr, 8);
        /* and clear the display */
        lc.clearDisplay(addr);
    }
}

void loop()
{
    for (uint8_t addr = 0; addr < SCREEN_CNT; addr++) {
        displayString_P(lc, texte, addr, 1500, true, ROTATION_90);
    }
}

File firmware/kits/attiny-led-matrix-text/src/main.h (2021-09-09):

#ifndef Main_h
#define Main_h

#include "LedControl.h"

#define PIN_LED_CLK    2
#define PIN_LED_CS     1
#define PIN_LED_DATA   0

#define PIN_BTN_A   3
#define PIN_BTN_B   4

#define LED_MATRIX_CNT 4

LedControl lc = LedControl(PIN_LED_DATA, PIN_LED_CLK, PIN_LED_CS, LED_MATRIX_CNT);

#include <avr/pgmspace.h>

//
// FACE_NAME "IBM BIOS 8x8"
//
// 0-31,127 : Code page 437, cf. https://en.wikipedia.org/wiki/Code_page_437
// 32-126   : ASCII
// 160-255  : ISO-8859-1, cf. https://en.wikipedia.org/wiki/ISO/IEC_8859-1

const uint8_t font8x8_ib8x8u[224][8] PROGMEM = {
    // ---------------------------  0-127 ---------------------------
    {0x00, 0x00, 0x00, 0x00, 0x00, 0x00, 0x00, 0x00},  // 0000 (uni0000.dup1)
    {0x7e, 0x81, 0xa5, 0x81, 0xbd, 0x99, 0x81, 0x7e},  // 0001 (uni0001)
    {0x7e, 0xff, 0xdb, 0xff, 0xc3, 0xe7, 0xff, 0x7e},  // 0002 (uni0002)
    {0x6c, 0xfe, 0xfe, 0xfe, 0x7c, 0x38, 0x10, 0x00},  // 0003 (uni0003)
    {0x10, 0x38, 0x7c, 0xfe, 0x7c, 0x38, 0x10, 0x00},  // 0004 (uni0004)
    {0x38, 0x7c, 0x38, 0xfe, 0xfe, 0x7c, 0x38, 0x7c},  // 0005 (uni0005)
    {0x10, 0x10, 0x38, 0x7c, 0xfe, 0x7c, 0x38, 0x7c},  // 0006 (uni0006)
    {0x00, 0x00, 0x18, 0x3c, 0x3c, 0x18, 0x00, 0x00},  // 0007 (uni0007)
    {0xff, 0xff, 0xe7, 0xc3, 0xc3, 0xe7, 0xff, 0xff},  // 0008 (uni0008)
    {0x00, 0x3c, 0x66, 0x42, 0x42, 0x66, 0x3c, 0x00},  // 0009 (uni0009)
    {0xff, 0xc3, 0x99, 0xbd, 0xbd, 0x99, 0xc3, 0xff},  // 000a (uni000A)
    {0x0f, 0x07, 0x0f, 0x7d, 0xcc, 0xcc, 0xcc, 0x78},  // 000b (uni000B)
    {0x3c, 0x66, 0x66, 0x66, 0x3c, 0x18, 0x7e, 0x18},  // 000c (uni000C)
    {0x3f, 0x33, 0x3f, 0x30, 0x30, 0x70, 0xf0, 0xe0},  // 000d (uni000D)
    {0x7f, 0x63, 0x7f, 0x63, 0x63, 0x67, 0xe6, 0xc0},  // 000e (uni000E)
    {0x99, 0x5a, 0x3c, 0xe7, 0xe7, 0x3c, 0x5a, 0x99},  // 000f (uni000F)
    {0x80, 0xe0, 0xf8, 0xfe, 0xf8, 0xe0, 0x80, 0x00},  // 0010 (uni0010)
    {0x02, 0x0e, 0x3e, 0xfe, 0x3e, 0x0e, 0x02, 0x00},  // 0011 (uni0011)
    {0x18, 0x3c, 0x7e, 0x18, 0x18, 0x7e, 0x3c, 0x18},  // 0012 (uni0012)
    {0x66, 0x66, 0x66, 0x66, 0x66, 0x00, 0x66, 0x00},  // 0013 (uni0013)
    {0x7f, 0xdb, 0xdb, 0x7b, 0x1b, 0x1b, 0x1b, 0x00},  // 0014 (uni0014)
    {0x3e, 0x63, 0x38, 0x6c, 0x6c, 0x38, 0xcc, 0x78},  // 0015 (uni0015)
    {0x00, 0x00, 0x00, 0x00, 0x7e, 0x7e, 0x7e, 0x00},  // 0016 (uni0016)
    {0x18, 0x3c, 0x7e, 0x18, 0x7e, 0x3c, 0x18, 0xff},  // 0017 (uni0017)
    {0x18, 0x3c, 0x7e, 0x18, 0x18, 0x18, 0x18, 0x00},  // 0018 (uni0018)
    {0x18, 0x18, 0x18, 0x18, 0x7e, 0x3c, 0x18, 0x00},  // 0019 (uni0019)
    {0x00, 0x18, 0x0c, 0xfe, 0x0c, 0x18, 0x00, 0x00},  // 001a (uni001A)
    {0x00, 0x30, 0x60, 0xfe, 0x60, 0x30, 0x00, 0x00},  // 001b (uni001B)
    {0x00, 0x00, 0xc0, 0xc0, 0xc0, 0xfe, 0x00, 0x00},  // 001c (uni001C)
    {0x00, 0x24, 0x66, 0xff, 0x66, 0x24, 0x00, 0x00},  // 001d (uni001D)
    {0x00, 0x18, 0x3c, 0x7e, 0xff, 0xff, 0x00, 0x00},  // 001e (uni001E)
    {0x00, 0xff, 0xff, 0x7e, 0x3c, 0x18, 0x00, 0x00},  // 001f (uni001F)
    {0x00, 0x00, 0x00, 0x00, 0x00, 0x00, 0x00, 0x00},  // 0020 (space)
    {0x30, 0x78, 0x78, 0x30, 0x30, 0x00, 0x30, 0x00},  // 0021 (exclam)
    {0x6c, 0x6c, 0x6c, 0x00, 0x00, 0x00, 0x00, 0x00},  // 0022 (quotedbl)
    {0x6c, 0x6c, 0xfe, 0x6c, 0xfe, 0x6c, 0x6c, 0x00},  // 0023 (numbersign)
    {0x30, 0x7c, 0xc0, 0x78, 0x0c, 0xf8, 0x30, 0x00},  // 0024 (dollar)
    {0x00, 0xc6, 0xcc, 0x18, 0x30, 0x66, 0xc6, 0x00},  // 0025 (percent)
    {0x38, 0x6c, 0x38, 0x76, 0xdc, 0xcc, 0x76, 0x00},  // 0026 (ampersand)
    {0x60, 0x60, 0xc0, 0x00, 0x00, 0x00, 0x00, 0x00},  // 0027 (quotesingle)
    {0x18, 0x30, 0x60, 0x60, 0x60, 0x30, 0x18, 0x00},  // 0028 (parenleft)
    {0x60, 0x30, 0x18, 0x18, 0x18, 0x30, 0x60, 0x00},  // 0029 (parenright)
    {0x00, 0x66, 0x3c, 0xff, 0x3c, 0x66, 0x00, 0x00},  // 002a (asterisk)
    {0x00, 0x30, 0x30, 0xfc, 0x30, 0x30, 0x00, 0x00},  // 002b (plus)
    {0x00, 0x00, 0x00, 0x00, 0x00, 0x30, 0x30, 0x60},  // 002c (comma)
    {0x00, 0x00, 0x00, 0xfc, 0x00, 0x00, 0x00, 0x00},  // 002d (hyphen)
    {0x00, 0x00, 0x00, 0x00, 0x00, 0x30, 0x30, 0x00},  // 002e (period)
    {0x06, 0x0c, 0x18, 0x30, 0x60, 0xc0, 0x80, 0x00},  // 002f (slash)
    {0x7c, 0xc6, 0xce, 0xde, 0xf6, 0xe6, 0x7c, 0x00},  // 0030 (zero)
    {0x30, 0x70, 0x30, 0x30, 0x30, 0x30, 0xfc, 0x00},  // 0031 (one)
    {0x78, 0xcc, 0x0c, 0x38, 0x60, 0xc4, 0xfc, 0x00},  // 0032 (two)
    {0x78, 0xcc, 0x0c, 0x38, 0x0c, 0xcc, 0x78, 0x00},  // 0033 (three)
    {0x1c, 0x3c, 0x6c, 0xcc, 0xfe, 0x0c, 0x1e, 0x00},  // 0034 (four)
    {0xfc, 0xc0, 0xf8, 0x0c, 0x0c, 0xcc, 0x78, 0x00},  // 0035 (five)
    {0x38, 0x60, 0xc0, 0xf8, 0xcc, 0xcc, 0x78, 0x00},  // 0036 (six)
    {0xfc, 0xcc, 0x0c, 0x18, 0x30, 0x30, 0x30, 0x00},  // 0037 (seven)
    {0x78, 0xcc, 0xcc, 0x78, 0xcc, 0xcc, 0x78, 0x00},  // 0038 (eight)
    {0x78, 0xcc, 0xcc, 0x7c, 0x0c, 0x18, 0x70, 0x00},  // 0039 (nine)
    {0x00, 0x30, 0x30, 0x00, 0x00, 0x30, 0x30, 0x00},  // 003a (colon)
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

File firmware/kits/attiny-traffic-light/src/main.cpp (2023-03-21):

#include <Arduino.h>

#ifdef REV_A
#define PIN_BTN 4
#define PIN_GRN 0
#define PIN_YLW 1
#define PIN_RED 2
#ifdef FEATURES_ARROW
#define PIN_ARR 3
#endif
#endif

#ifdef REV_B
#define PIN_BTN 3
#define PIN_GRN 4
#define PIN_YLW 1
#define PIN_RED 0
#ifdef FEATURES_ARROW
#define PIN_ARR 2
#endif
#endif

#ifdef FEATURES_ARROW
#define PIN_ARR 3
#endif

#define LED_OFF LOW
#define LED_ON HIGH

#define BTN_OFF HIGH
#define BTN_ON LOW

#define OFF_AFTER_SEC 5

enum State
{
  OFF,
  ON,
  GREEN,
  YELLOW_TO_RED,
  RED,
  YELLOW_TO_GREEN,
  TO_OFF
};

State current_state = OFF;

void do_demo_pin(uint8_t pin)
{
  for (uint8_t x = 0; x < 0xff; x++)
  {
    analogWrite(pin, x);
    delay(1);
  }
  for (uint8_t x = 0xff; x > 0; x--)
  {
    analogWrite(pin, x);
    delay(1);
  }
  analogWrite(pin, 0);
}

void setup()
{
  pinMode(PIN_BTN, INPUT);
  pinMode(PIN_GRN, OUTPUT);
  pinMode(PIN_YLW, OUTPUT);
  pinMode(PIN_RED, OUTPUT);

#ifdef FEATURES_ARROW
  pinMode(PIN_ARR, OUTPUT);
  digitalWrite(PIN_ARR, LOW);
#endif

#ifdef DEMO_MODE
  while (1)
  {
    do_demo_pin(PIN_GRN);
    do_demo_pin(PIN_YLW);
    do_demo_pin(PIN_RED);
  }
#endif
}

uint16_t last_off = 0;
#ifdef FEATURES_ARROW
uint8_t arrow_flag = 0;
uint8_t arrow_seq = 0;
#endif

void loop()
{
  uint8_t btn_state = digitalRead(PIN_BTN);
  if (btn_state == BTN_OFF)
  {
    last_off = millis() >> 10;
  }
  if (btn_state == BTN_ON)
  {
    uint16_t now = millis() >> 10;
    uint16_t sec_on = now - last_off;
    // check if long press
    if (sec_on >= OFF_AFTER_SEC)
    {
      current_state = TO_OFF;
    }
  }

  switch (current_state)
  {
  case TO_OFF:
    if (btn_state == BTN_ON)
    {
      digitalWrite(PIN_YLW, OFF);
      digitalWrite(PIN_RED, OFF);
      digitalWrite(PIN_GRN, OFF);
    }
    if (btn_state == BTN_OFF)
    {
      current_state = OFF;
    }
    break;

  case OFF:
    if (btn_state == BTN_OFF)
    {
      uint16_t seconds = millis() >> 10;
      uint8_t yellow_state = seconds % 2;
      digitalWrite(PIN_YLW, yellow_state);
    }
    if (btn_state == BTN_ON)
    {
      current_state = ON;
    }
    break;

  case ON:
    if (btn_state == BTN_ON)
    {
      digitalWrite(PIN_YLW, ON);
    }
    if (btn_state == BTN_OFF)
    {
      current_state = GREEN;
    }
    break;

  case GREEN:
    if (btn_state == BTN_OFF)
    {
      digitalWrite(PIN_RED, LED_OFF);
      digitalWrite(PIN_YLW, LED_OFF);
      digitalWrite(PIN_GRN, LED_ON);
    }
    if (btn_state == BTN_ON)
    {
      current_state = YELLOW_TO_RED;
    }
    break;

  case YELLOW_TO_RED:
    if (btn_state == BTN_ON)
    {
      digitalWrite(PIN_GRN, LED_OFF);
      digitalWrite(PIN_YLW, LED_ON);
    }
    if (btn_state == BTN_OFF)
    {
      current_state = RED;
    }
    break;

  case RED:
    if (btn_state == BTN_OFF)
    {
      digitalWrite(PIN_YLW, LED_OFF);
      digitalWrite(PIN_RED, LED_ON);
#ifdef FEATURES_ARROW
      if (arrow_flag == 0)
      {
        bool should_switch_on = arrow_seq++ % 2 == 0;
        //millis() % 2 == 0;
        if (should_switch_on)
          digitalWrite(PIN_ARR, LED_ON);
        arrow_flag = 1;
      }
#endif
    }
    if (btn_state == BTN_ON)
    {
      current_state = YELLOW_TO_GREEN;
#ifdef FEATURES_ARROW
      arrow_flag = 0;
#endif
    }
    break;

  case YELLOW_TO_GREEN:
    if (btn_state == BTN_ON)
    {
#ifdef FEATURES_ARROW
      digitalWrite(PIN_ARR, LED_OFF);
#endif
      digitalWrite(PIN_RED, LED_ON);
      digitalWrite(PIN_YLW, LED_ON);
    }
    if (btn_state == BTN_OFF)
    {
      current_state = GREEN;
    }
    break;
  }
}

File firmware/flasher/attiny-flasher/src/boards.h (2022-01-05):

#ifndef _BOARDS_H_
#define _BOARDS_H_

// Connection with host PC (HW serial)
#define BAUDRATE_IN 115200

// Connection with target MCU (SW serial)
#define BAUDRATE_OUT 115200

// ======= REVISION CAPABILITES DEFINITION ============

#if defined(FLASHER_REV_C)
#define BUF_74HC125D
// Tiny-linked Serial pins
#define PIN_SERIAL_RX 5
#define PIN_SERIAL_TX 4 // sometimes 2
#endif

#if defined(FLASHER_REV_D)
#define BUF_74HC125D
// Tiny-linked Serial pins
#define PIN_SERIAL_RX 5
#define PIN_SERIAL_TX 4
#define SERIAL_SENSOR_EN
#define SERIAL_SENSOR_PIN A3
#endif

#if defined(FLASHER_REV_E) || defined(FLASHER_REV_F) || defined(FLASHER_REV_G) || defined(FLASHER_REV_H)
#define REV_D_TWO_PIN_RESET
#define HVSP_PROGRAMMER
#define SERIAL_SENSOR_EN
#define SERIAL_SENSOR_PIN A3
#define BUF_74HC241

// Tiny-linked Serial pins
#define PIN_SERIAL_RX 4
#define PIN_SERIAL_TX 5

// ============== RESET MODES DEFINITION ==============
#define RESET_SENSOR_EN
#define RESET_SENSOR_PIN 2
#define RESET_SENSOR_WRITE(X)          \
    pinMode(RESET_SENSOR_PIN, OUTPUT); \
    digitalWrite(RESET_SENSOR_PIN, X);
#define RESET_SENSOR_READ \
    pinMode(RESET_SENSOR_PIN, INPUT);
#endif

#ifdef MEGAFLASHER_REV_F
#define MEGAFLASHER
#define BUF_74HC125D
// Tiny-linked Serial pins
#define PIN_SERIAL_RX 4
#define PIN_SERIAL_TX 5
#define SERIAL_SENSOR_EN
#define SERIAL_SENSOR_PIN A3
#endif

#define RESET 10
#if defined(REV_D_TWO_PIN_RESET)
#define RESET_PULL A2 // Need another pin to pull it down properly
#endif

// Enable output buffer, active HIGH on 74HC126D, active LOW on 74HC125D
#if defined(FLASHER_REV_F) || defined(FLASHER_REV_G) || defined(FLASHER_REV_H) || defined(MEGAFLASHER_REV_F) 
#define PIN_BUFEN A1
#else
#define PIN_BUFEN 6
#endif

#ifdef BUF_74HC126D
#define _BUFFER_HV_PROG ;
#define _BUFFER_INIT            \
    pinMode(PIN_BUFEN, OUTPUT); \
#define _BUFFER_ON          \
        digitalWrite(PIN_BUFEN, HIGH);
#define _BUFFER_OFF \
    digitalWrite(PIN_BUFEN, LOW);
#endif

#ifdef BUF_74HC125D
#define _BUFFER_HV_PROG ;
#define _BUFFER_INIT \
    pinMode(PIN_BUFEN, OUTPUT);
#define _BUFFER_ON \
    digitalWrite(PIN_BUFEN, LOW);
#define _BUFFER_OFF \
    digitalWrite(PIN_BUFEN, HIGH);
#endif

#ifdef BUF_74HC241
#define _BUFFER_HV_PROG         \
    pinMode(PIN_BUFEN, OUTPUT); \
    digitalWrite(PIN_BUFEN, LOW); \
    if (sserial != NULL) pinMode(PIN_SERIAL_TX, INPUT) // SERIAL_TX connected to HVSP_CSI
#define _BUFFER_INIT ;
#define _BUFFER_ON              \
    pinMode(PIN_BUFEN, OUTPUT); \
    digitalWrite(PIN_BUFEN, HIGH);
#define _BUFFER_OFF \
    pinMode(PIN_BUFEN, INPUT); \
    if (sserial != NULL) pinMode(PIN_SERIAL_TX, OUTPUT) // SERIAL_TX connected to HVSP_CSI
#endif

#if defined(REV_D_TWO_PIN_RESET)
#define _RESET_INIT         \
    pinMode(RESET, OUTPUT); \
    pinMode(RESET_PULL, OUTPUT);
#define _RESET_HIGH_12             \
    RESET_SENSOR_WRITE(HIGH);      \
    digitalWrite(RESET_PULL, LOW); \
    digitalWrite(RESET, HIGH);
#define _RESET_HIGH                \
    RESET_SENSOR_WRITE(LOW);       \
    digitalWrite(RESET_PULL, LOW); \
    digitalWrite(RESET, HIGH);
#define _RESET_LOW                  \
    digitalWrite(RESET, LOW);       \
    digitalWrite(RESET_PULL, HIGH); \
    RESET_SENSOR_WRITE(LOW);
#define _RESET_Z                   \
    digitalWrite(RESET_PULL, LOW); \
    digitalWrite(RESET, LOW);      \
    RESET_SENSOR_READ;
#else
#define _RESET_INIT ;
#define _RESET_HIGH_12 ;
#define _RESET_HIGH         \
    pinMode(RESET, OUTPUT); \
    digitalWrite(RESET, HIGH);
#define _RESET_LOW          \
    pinMode(RESET, OUTPUT); \
    digitalWrite(RESET, LOW);
#define _RESET_Z \
    pinMode(RESET, INPUT);
#endif

// ======= INDICATION PINS ============================

#define PULSE_TIME 10
#define LED_HB 9    // Heartbeat
#define LED_ERR 8   // Error
#define LED_PMODE 7 // Programm

#if defined(OLED_LIB_ADAFRUIT) || defined(OLED_LIB_TINY)
#define OLED_ENABLE
#endif

// ============== PIN MODES DEFINITION ==============

#define PIN_MOSI MOSI
#define PIN_MISO MISO
#define PIN_SCK SCK

#define SETUP_PINS_ISP         \
    pinMode(PIN_MOSI, OUTPUT); \
    pinMode(PIN_MISO, INPUT);  \
    pinMode(PIN_SCK, OUTPUT);

#define PIN_SCI 3
#define PIN_SCI_PORT PORTD
#define PIN_SCI_NUM PD3

#define PIN_SDO SCK
#define PIN_SDO_PORT PORTB
#define PIN_SDO_PIN PINB
#define PIN_SDO_NUM PB5

#define PIN_SII MISO
#define PIN_SII_PORT PORTB
#define PIN_SII_NUM PB4

#define PIN_SDI MOSI
#define PIN_SDI_PORT PORTB
#define PIN_SDI_NUM PB3

#define _SETUP_PINS_HVSP       \
    pinMode(PIN_SDI, OUTPUT); \
    pinMode(PIN_SII, OUTPUT); \
    pinMode(PIN_SCI, OUTPUT); \
    pinMode(PIN_SDO, INPUT);  

#define _SETUP_PINS_HVSP_INIT    \
    pinMode(PIN_SDO, OUTPUT);   \
    digitalWrite(PIN_SDI, LOW); \
    digitalWrite(PIN_SII, LOW); \
    digitalWrite(PIN_SDO, LOW);

#define HVSP_SDI_LOW \
    PIN_SDI_PORT &= ~_BV(PIN_SDI_NUM) // digitalWrite(PIN_SDI, LOW);
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

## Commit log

2021-03-02 Basic structure. Added hw files, added early firmware code
    [Gerber_BoardOutline.GKO, Gerber_BottomLayer.GBL, Gerber_BottomSilkLayer.GBO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]
2021-06-24 Added high voltage programmer code (not fully tested yet). Some restructuring and debugging added.
2021-06-28 inplemented sw serial switch (only checks once after reset)
    [boards.h, main.cpp, main.h]
2021-11-21 Flahser serial switch improvements
2021-12-09 Updated samples after testing new revision
2021-12-17 Features/hw docs (#1)
    * Added hw docs and started written down some readmes
    * Added software repo basic descriptions and links
    [Gerber_BoardOutline.GKO, Gerber_BottomLayer.GBL, Gerber_BottomSilkLayer.GBO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]
2023-03-21 Sync changes from the fork (#3)
    * Sync changes from the fork
    * build fixes
    ---------
    [main.cpp]
